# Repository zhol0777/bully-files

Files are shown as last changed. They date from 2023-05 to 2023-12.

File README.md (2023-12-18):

# bully-files

Bully is a keyboard designed by paaradiso keyboard design and zhol. It combines low typing angle, a plateless build, and modest but dignified design sensibilities. Its 13.5u width layout is designed for maximum compatibility with base kits that are missing minimum 40% keyboard support (“3-key”). Bully has a 22.4mm EKH, 4.0 degree angle, and bezels measuring 8mm and 3mm. 

The case files are provided in the [./case](./case/) directory, and alternative tops for HHKB layout (1.25u blocker) and WKL (1.25u blocker) are provided in their respective directories. 

This ran in a private run and public run by Coffee Break Keyboards in Q1 2023 and fulfilling Q2 2023.

## Required components
* Daughterboard
  * It is designed for [C3 Unified Daughterboard](https://github.com/Unified-Daughterboard/UDB-C-Legacy), but an updated daughterboard that takes JST-SH cables is provided [here](https://github.com/Unified-Daughterboard/UDB-C-JSH).
* Tadpoles
  * bully's PCB is fit into the case not with screws, but 8 injection molded rubber inserts named "tadpoles", from Geonworks.
  * [Files, courtesy Geon](https://geon.works/pages/tadpole-files)
* Screws
  * All screws are M2. Screws for daughterboard are 4mm, case screws are 6-ish mm.
* JST cable
  * As sold, bully took a 50mm 4-pin JST-SH cable. These cables are wired 1:1. I had no issues with Adafruit Qwiic JST SH cables sourced from Mouser. If you use an alternative connector on your PCB and daughterboard, you will need to ensure those cables are also 1:1.
* PCB
  * PCB edge cuts and plate files are provided in the [./misc](./misc/) directory. An electro-capacitive (commonly known as Topre, or NIZ Plum) compatible PCB is provided by sporkus [here](https://github.com/sporkus/capybully_keyboard). An alternative PCB compatible with Cherry MX and Alps switches is provided by sporkus [here](https://github.com/sporkus/bully2040_keyboard).
* Case feet.
  * bully uses [SKUF feet](https://github.com/Zambumon/SKUF).

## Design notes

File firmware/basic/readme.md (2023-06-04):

# mkh bully

* Keyboard Maintainer: [zhol0777](https://github.com/zhol0777)
* Hardware Supported: APM32F072
* Hardware Availability: [Coffee Break Keyboards](https://cbkbd.com/)

Make example for this keyboard (after setting up your build environment):

    qmk compile -kb zhol/bully -km default

Flashing example for this keyboard:

    qmk flash -kb zhol/bully -km default

See the [build environment setup](https://docs.qmk.fm/#/getting_started_build_tools) and the [make instructions](https://docs.qmk.fm/#/getting_started_make_guide) for more information. Brand new to QMK? Start with our [Complete Newbs Guide](https://docs.qmk.fm/#/newbs).

After flashing, you may see LIBUSB_ERROR_TIMEOUT; this is normal, simply tap the reset button once afterwards (or re-plug your PCB) and the keyboard should become operational again.

## Bootloader

Enter the bootloader in 3 ways:

* **Bootmagic reset**: Hold down the key at (0,0) in the matrix (usually the top left key or Escape) and plug in the keyboard
* **Physical reset button**: Press the button on the back of the PCB for at least three seconds
* **Keycode in layout**: Press the key mapped to `QK_BOOT` if it is available

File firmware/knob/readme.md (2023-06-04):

# mkh bully (now with knob)

* Keyboard Maintainer: [zhol0777](https://github.com/zhol0777)
* Hardware Supported: APM32F072
* Hardware Availability: Private Buy

Make example for this keyboard (after setting up your build environment):

    qmk compile -kb zhol/bully_knob -km default

Flashing example for this keyboard:

    qmk flash -kb zhol/bully_knob -km default

See the [build environment setup](https://docs.qmk.fm/#/getting_started_build_tools) and the [make instructions](https://docs.qmk.fm/#/getting_started_make_guide) for more information. Brand new to QMK? Start with our [Complete Newbs Guide](https://docs.qmk.fm/#/newbs).

After flashing, you may see LIBUSB_ERROR_TIMEOUT; this is normal, simply tap the reset button once afterwards (or re-plug your PCB) and the keyboard should become operational again.

## Bootloader

Enter the bootloader in 3 ways:

* **Bootmagic reset**: Hold down the key at (0,0) in the matrix (usually the top left key or Escape) and plug in the keyboard
* **Physical reset button**: Briefly press the button on the back of the PCB - some may have pads you must short instead
* **Keycode in layout**: Press the key mapped to `QK_BOOT` if it is available

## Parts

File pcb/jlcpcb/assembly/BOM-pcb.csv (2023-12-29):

Comment | Designator | Footprint | LCSC
10nF | C7 | C_0402_1005Metric | C15195
4.7uF | C10,C3,C8 | C_0402_1005Metric | C23733
100k | R2 | R_0402_1005Metric | C25741
10k | R1,R3 | R_0402_1005Metric | C25744
DB | J1 | JST_SH_SM04B-SRSS-TB_1x04-1MP_P1.00mm_Horizontal | C2845363
100nF | C1,C2,C4,C5 | C_0402_1005Metric | C307331
SW_Push | SW54 | SW_SPST_TL3342 | C318884
1uF | C11,C12,C6,C9 | C_0402_1005Metric | C52923
XC6206PxxxMR | U2 | SOT-23 | C5446
D_Small | D1,D10,D11,D12,D13,D14,D15,D16,D17,D18,D19,D2,D20,D21,D22,D23,D24,D25,D26,D27,D28,D29,D3,D30,D31,D32,D33,D34,D35,D36,D37,D38,D39,D4,D40,D41,D42,D43,D44,D45,D46,D5,D6,D7,D8,D9 | D_SOD-123 | C81598
2N7002 | Q1 | SOT-23 | C8545
STM32F072C8Tx | U1 | LQFP-48_7x7mm_P0.5mm | C915660
MX_SW_solder | SW10 | SW_MX_1u
MX_SW_solder | SW48 | SW_MX_1u
MX_SW_solder | SW49 | SW_MX_1.25u
MX_SW_solder | SW41 | SW_MX_1u
MX_SW_solder | SW25 | SW_MX_1u
MX_SW_solder | SW1 | SW_MX_1.75u
MX_SW_solder | SW57 | SW_MX_1.5u
MX_SW_solder | SW8 | SW_MX_1u
MX_SW_solder | SW60 | SW_MX_1.25u
MX_SW_solder | SW55 | SW_MX_1.25u
MX_SW_solder | SW59 | SW_MX_1.25u
MX_SW_solder | SW15 | SW_MX_1u
MX_SW_solder | SW36 | SW_MX_1u
MX_SW_solder | SW33 | SW_MX_1u
MX_SW_solder | SW6 | SW_MX_1.25u
MX_SW_solder | SW30 | SW_MX_1u
MX_SW_solder | SW31 | SW_MX_1u
MX_SW_solder | SW21 | SW_MX_1u
MX_SW_solder | SW7 | SW_MX_1.25u
MX_stab | S5 | STAB_MX_6u
MX_SW_solder | SW13 | SW_MX_1u
MX_SW_solder | SW5 | SW_MX_1u
MX_SW_solder | SW16 | SW_MX_1.25u
MX_SW_solder | SW24 | SW_MX_1u
MX_SW_solder | SW23 | SW_MX_1u
MX_SW_solder | SW46 | SW_MX_1u
MX_stab | S2 | STAB_MX_P_2.25u
MX_SW_solder | SW26 | SW_MX_1u
MX_stab | S8 | STAB_MX_P_2.75u
MX_SW_solder | SW29 | SW_MX_1u
MX_SW_solder | SW43 | SW_MX_1u
MX_SW_solder | SW37 | SW_MX_1u
MX_SW_solder | SW50 | SW_MX_1.25u
MX_SW_solder | SW2 | SW_MX_1.5u
MX_SW_solder | SW56 | SW_MX_1u
MX_SW_solder | SW47 | SW_MX_1u
MX_SW_solder | SW35 | SW_MX_1u
MX_stab | S4 | STAB_MX_P_2.25u
MX_SW_solder | SW42 | SW_MX_1u
MX_SW_solder | SW32 | SW_MX_1u
MX_SW_solder | SW19 | SW_MX_1u
MX_SW_solder | SW4 | SW_MX_1.75u_stp
MX_SW_solder | SW40 | SW_MX_1u
MX_SW_solder | SW9 | SW_MX_1u
MX_SW_solder | SW52 | SW_MX_1u
MX_stab | S7 | STAB_MX_P_3u
MX_SW_solder | SW12 | SW_MX_1.5u
MX_stab | S6 | STAB_MX_6.25u
MX_SW_solder | SW51 | SW_MX_1u
MX_SW_solder | SW34 | SW_MX_1u
MX_SW_solder | SW39 | SW_MX_1u
MX_SW_solder | SW53 | SW_MX_1.75u
MX_SW_solder | SW27 | SW_MX_1u
MX_stab | S1 | STAB_MX_P_2u
MX_SW_solder | SW22 | SW_MX_1u
MX_SW_solder | SW20 | SW_MX_1u
MX_SW_solder | SW45 | SW_MX_1.25u
MX_SW_solder | SW38 | SW_MX_1u
MX_SW_solder | SW44 | SW_MX_1.5u
MX_SW_solder | SW28 | SW_MX_1u
MX_SW_solder | SW17 | SW_MX_1u
MX_SW_solder | SW18 | SW_MX_1u
MX_SW_solder | SW14 | SW_MX_1u
MX_SW_solder | SW3 | SW_MX_1.5u
MX_stab | S3 | STAB_MX_P_3u
MX_SW_solder | SW11 | SW_MX_1.25u
MX_SW_solder | SW58 | SW_MX_1u
MX_SW_solder | SW61 | SW_MX_1u
MX_stab | S9 | STAB_MX_P_2.25u

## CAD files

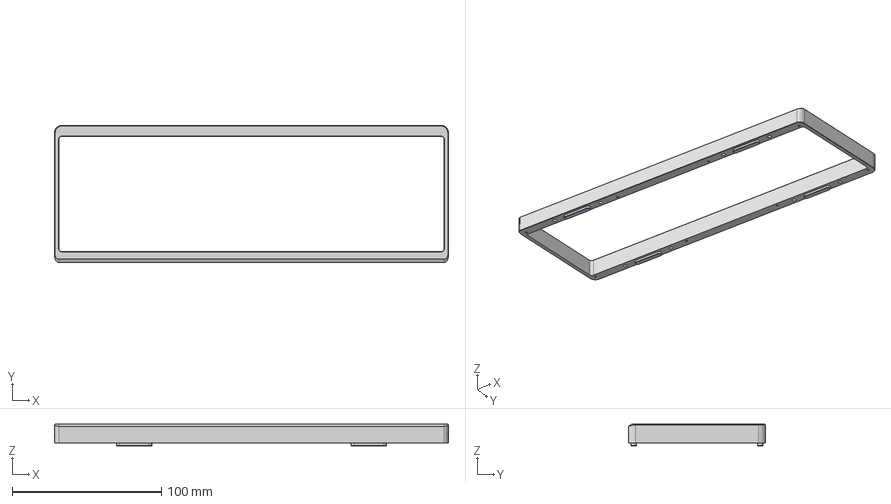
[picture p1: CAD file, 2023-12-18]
case/Top.step
264.1 x 92.1 x 14.7 mm

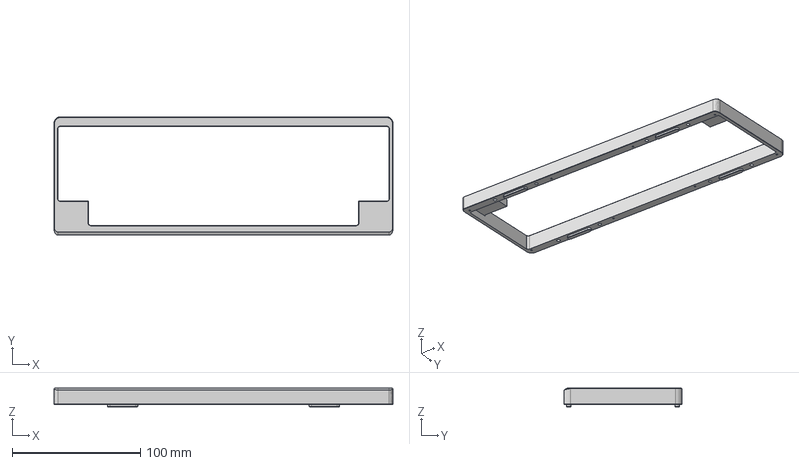
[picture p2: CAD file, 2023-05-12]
hhkb_top/Top.step
264.1 x 92.1 x 14.7 mm

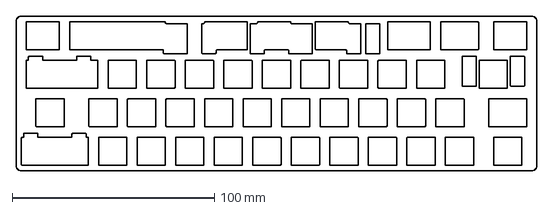
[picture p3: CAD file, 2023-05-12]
misc/plate-2.dxf
257.2 x 76.2 mm

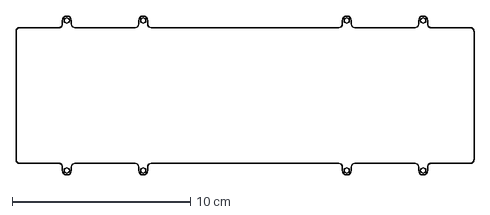
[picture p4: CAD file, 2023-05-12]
pcb/edgecuts.dxf
25.7 x 8.92 cm

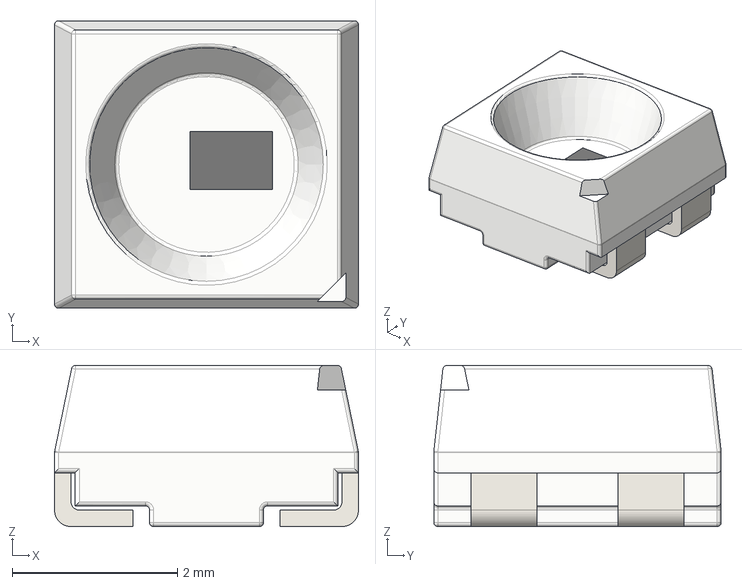
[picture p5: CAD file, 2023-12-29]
pcb/marbastlib/3d/LED_WS2812B-MINI.step
3.68 x 3.48 x 1.95 mm

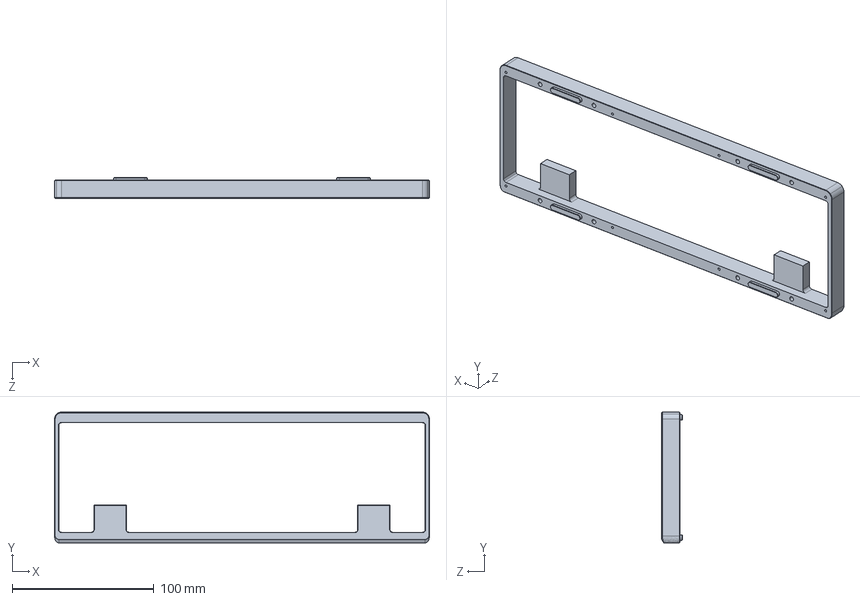
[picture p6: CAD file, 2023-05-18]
wkl_top/wkl_6u.STEP
264.1 x 92.1 x 14.7 mm

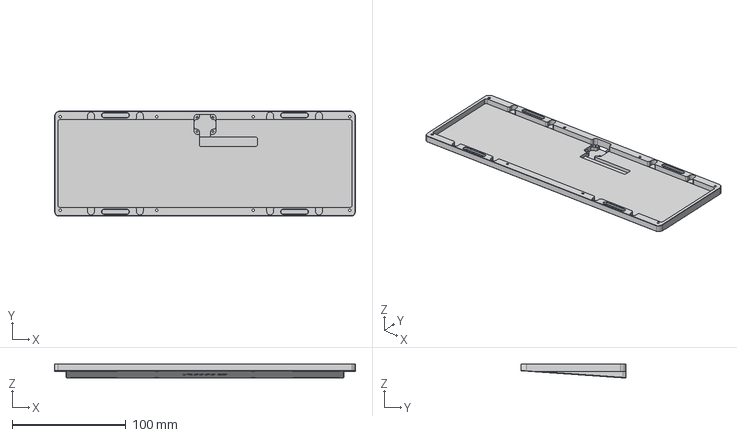
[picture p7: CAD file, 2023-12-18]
case/Bottom-gb.step
264.1 x 92.1 x 12.4 mm

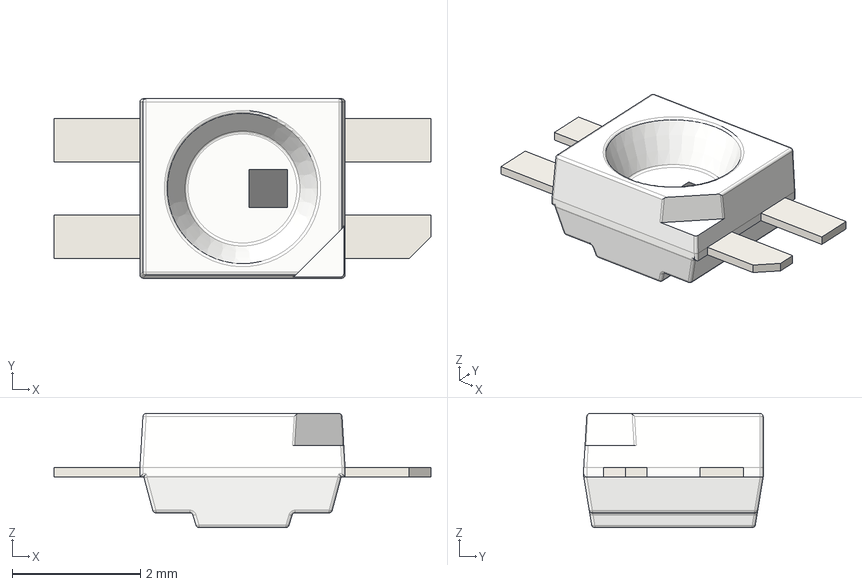
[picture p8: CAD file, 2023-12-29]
pcb/marbastlib/3d/LED_SK6812MINI-E.step
5.88 x 2.80 x 1.78 mm

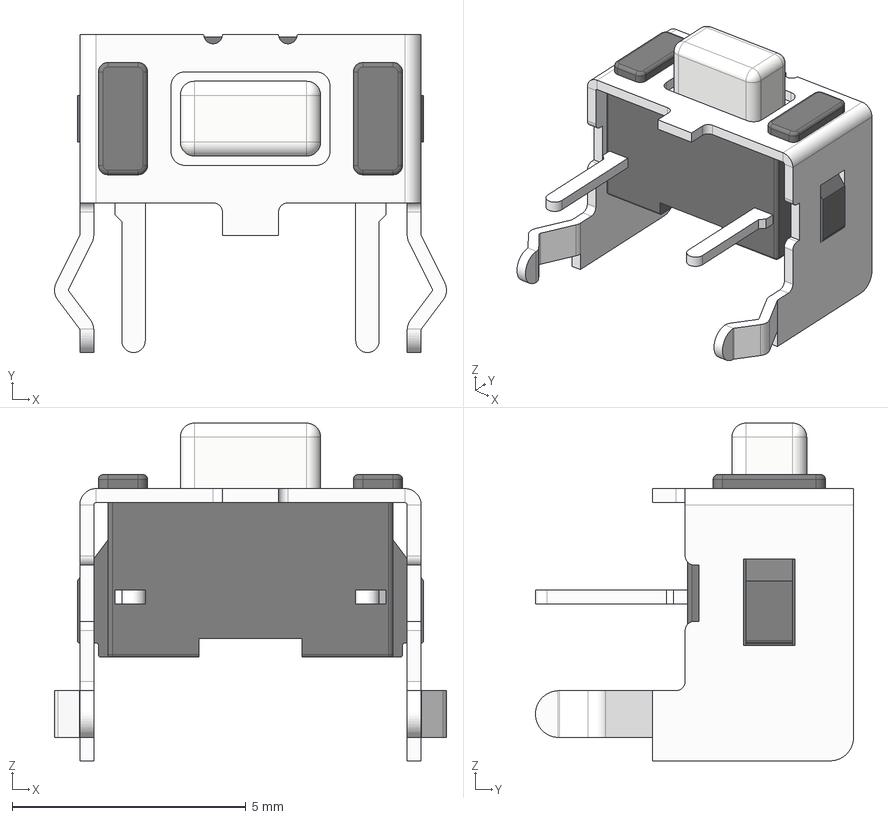
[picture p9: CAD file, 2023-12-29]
pcb/marbastlib/3d/SW_SKHLLC.step
8.38 x 6.80 x 7.22 mm

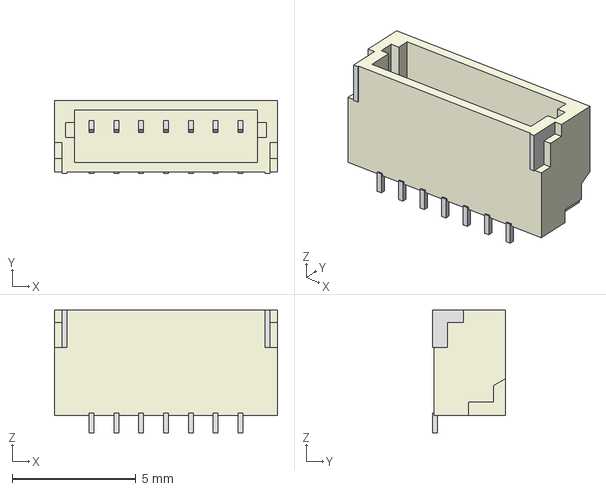
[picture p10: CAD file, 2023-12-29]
pcb/marbastlib/3d/CON_SM07B-SRSS-TB.step
9.00 x 2.96 x 4.95 mm

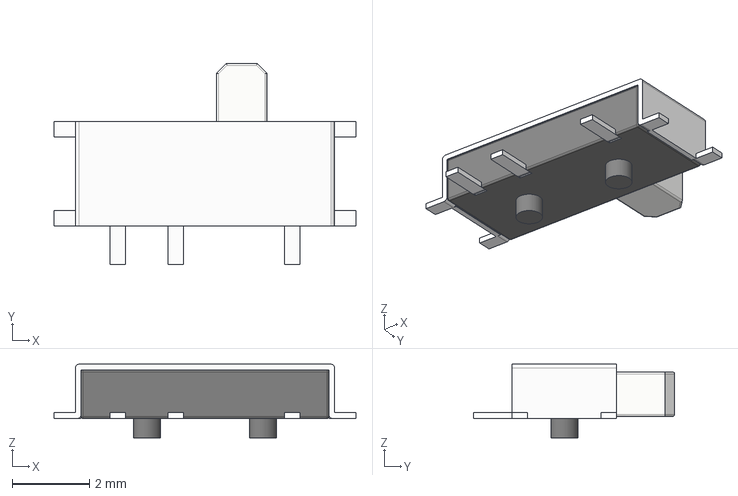
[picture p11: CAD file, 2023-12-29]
pcb/marbastlib/3d/SW_MSK12C02.step
7.80 x 5.20 x 1.90 mm

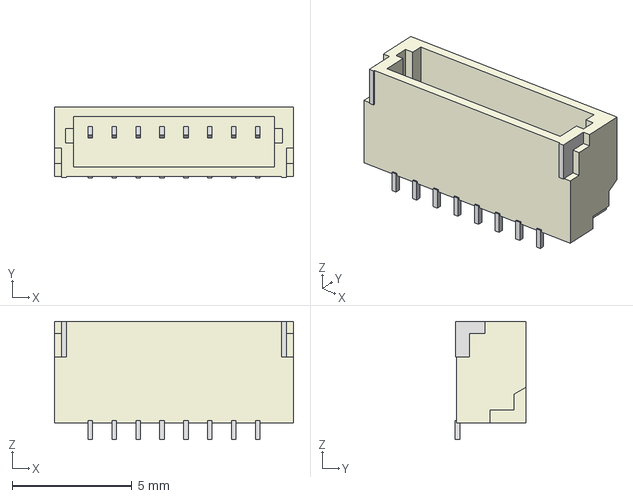
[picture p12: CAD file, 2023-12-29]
pcb/marbastlib/3d/CON_SM08B-SRSS-TB.step
10.0 x 2.96 x 4.95 mm

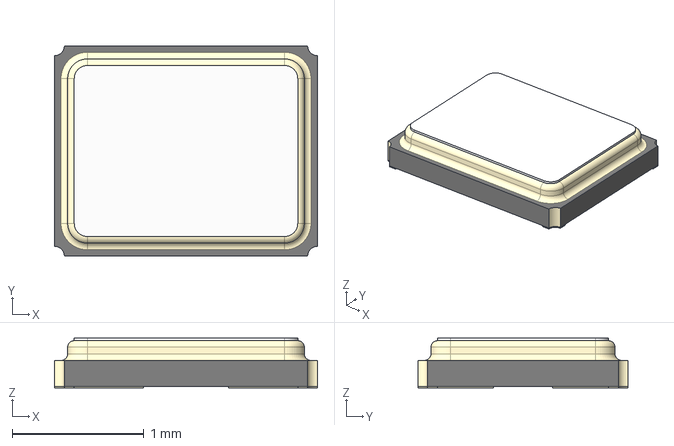
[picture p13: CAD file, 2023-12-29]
pcb/marbastlib/3d/Crystal_FA-128.step
2.00 x 1.60 x 0.38 mm

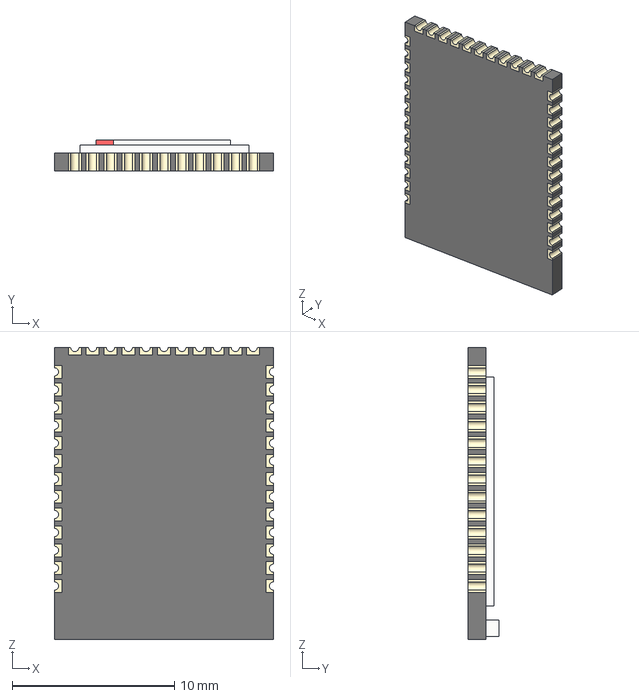
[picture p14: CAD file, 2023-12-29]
pcb/marbastlib/3d/holyiot_18010_nRF52840.step
13.5 x 1.92 x 18.0 mm

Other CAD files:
pcb/marbastlib/3d/MSK12C02.step
pcb/marbastlib/3d/ROT_EC11E.step
pcb/marbastlib/3d/SW_SSSS213100.step
pcb/marbastlib/3d/ROT_EC11N.step
pcb/marbastlib/3d/CON_BM02B-ACHSS.step
pcb/marbastlib/3d/CON_MJ-4PP-9.step
pcb/marbastlib/3d/CON_SM02B-SRSS-TB.step
pcb/marbastlib/3d/CON_SM04B-SRSS-TB.step
pcb/marbastlib/3d/CON_SM05B-SRSS-TB.step
pcb/marbastlib/3d/CON_SM06B-SRSS-TB.step
pcb/marbastlib/3d/CON_SM13B-SRSS-TB.step
pcb/marbastlib/3d/CON_TYPE-C-31-M-12.step
pcb/marbastlib/3d/CON_TYPE-C-31-M-14.step
pcb/marbastlib/3d/HS_Kailh_Choc.step
pcb/marbastlib/3d/HS_Kailh_MX.step
pcb/marbastlib/3d/LED_WS2812_2020.step
pcb/marbastlib/3d/PNT_RKJXU1210006.step
pcb/marbastlib/3d/PNT_psp1000.step
pcb/marbastlib/3d/SW_ESP3020.step
pcb/marbastlib/3d/SW_SSSS223900.step
pcb/marbastlib/3d/moko_mk08a_nRF52840.step

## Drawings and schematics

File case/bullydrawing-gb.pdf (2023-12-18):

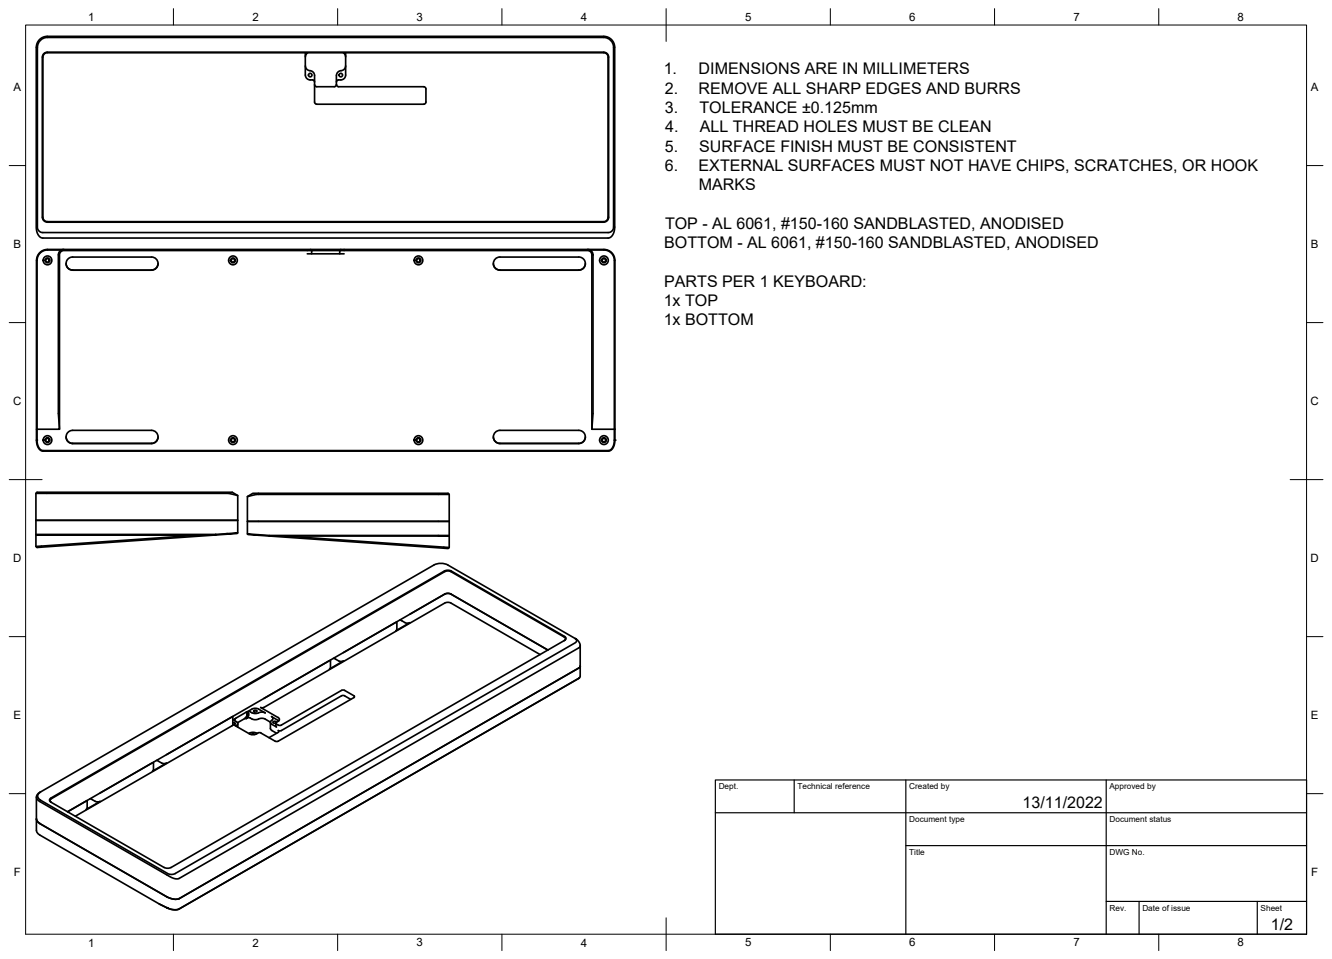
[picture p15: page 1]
Title; DWG No.; Rev.; Date of issue; Sheet

1. DIMENSIONS ARE IN MILLIMETERS
2. REMOVE ALL SHARP EDGES AND BURRS
3. TOLERANCE ±0.125mm
4. ALL THREAD HOLES MUST BE CLEAN
5. SURFACE FINISH MUST BE CONSISTENT
6. EXTERNAL SURFACES MUST NOT HAVE CHIPS, SCRATCHES, OR HOOK
MARKS

TOP - AL 6061, #150-160 SANDBLASTED, ANODISED
BOTTOM - AL 6061, #150-160 SANDBLASTED, ANODISED

PARTS PER 1 KEYBOARD:
1x TOP
1x BOTTOM

Dept. | Technical reference | Created by 13/11/2022 | Approved by

Document type | Document status

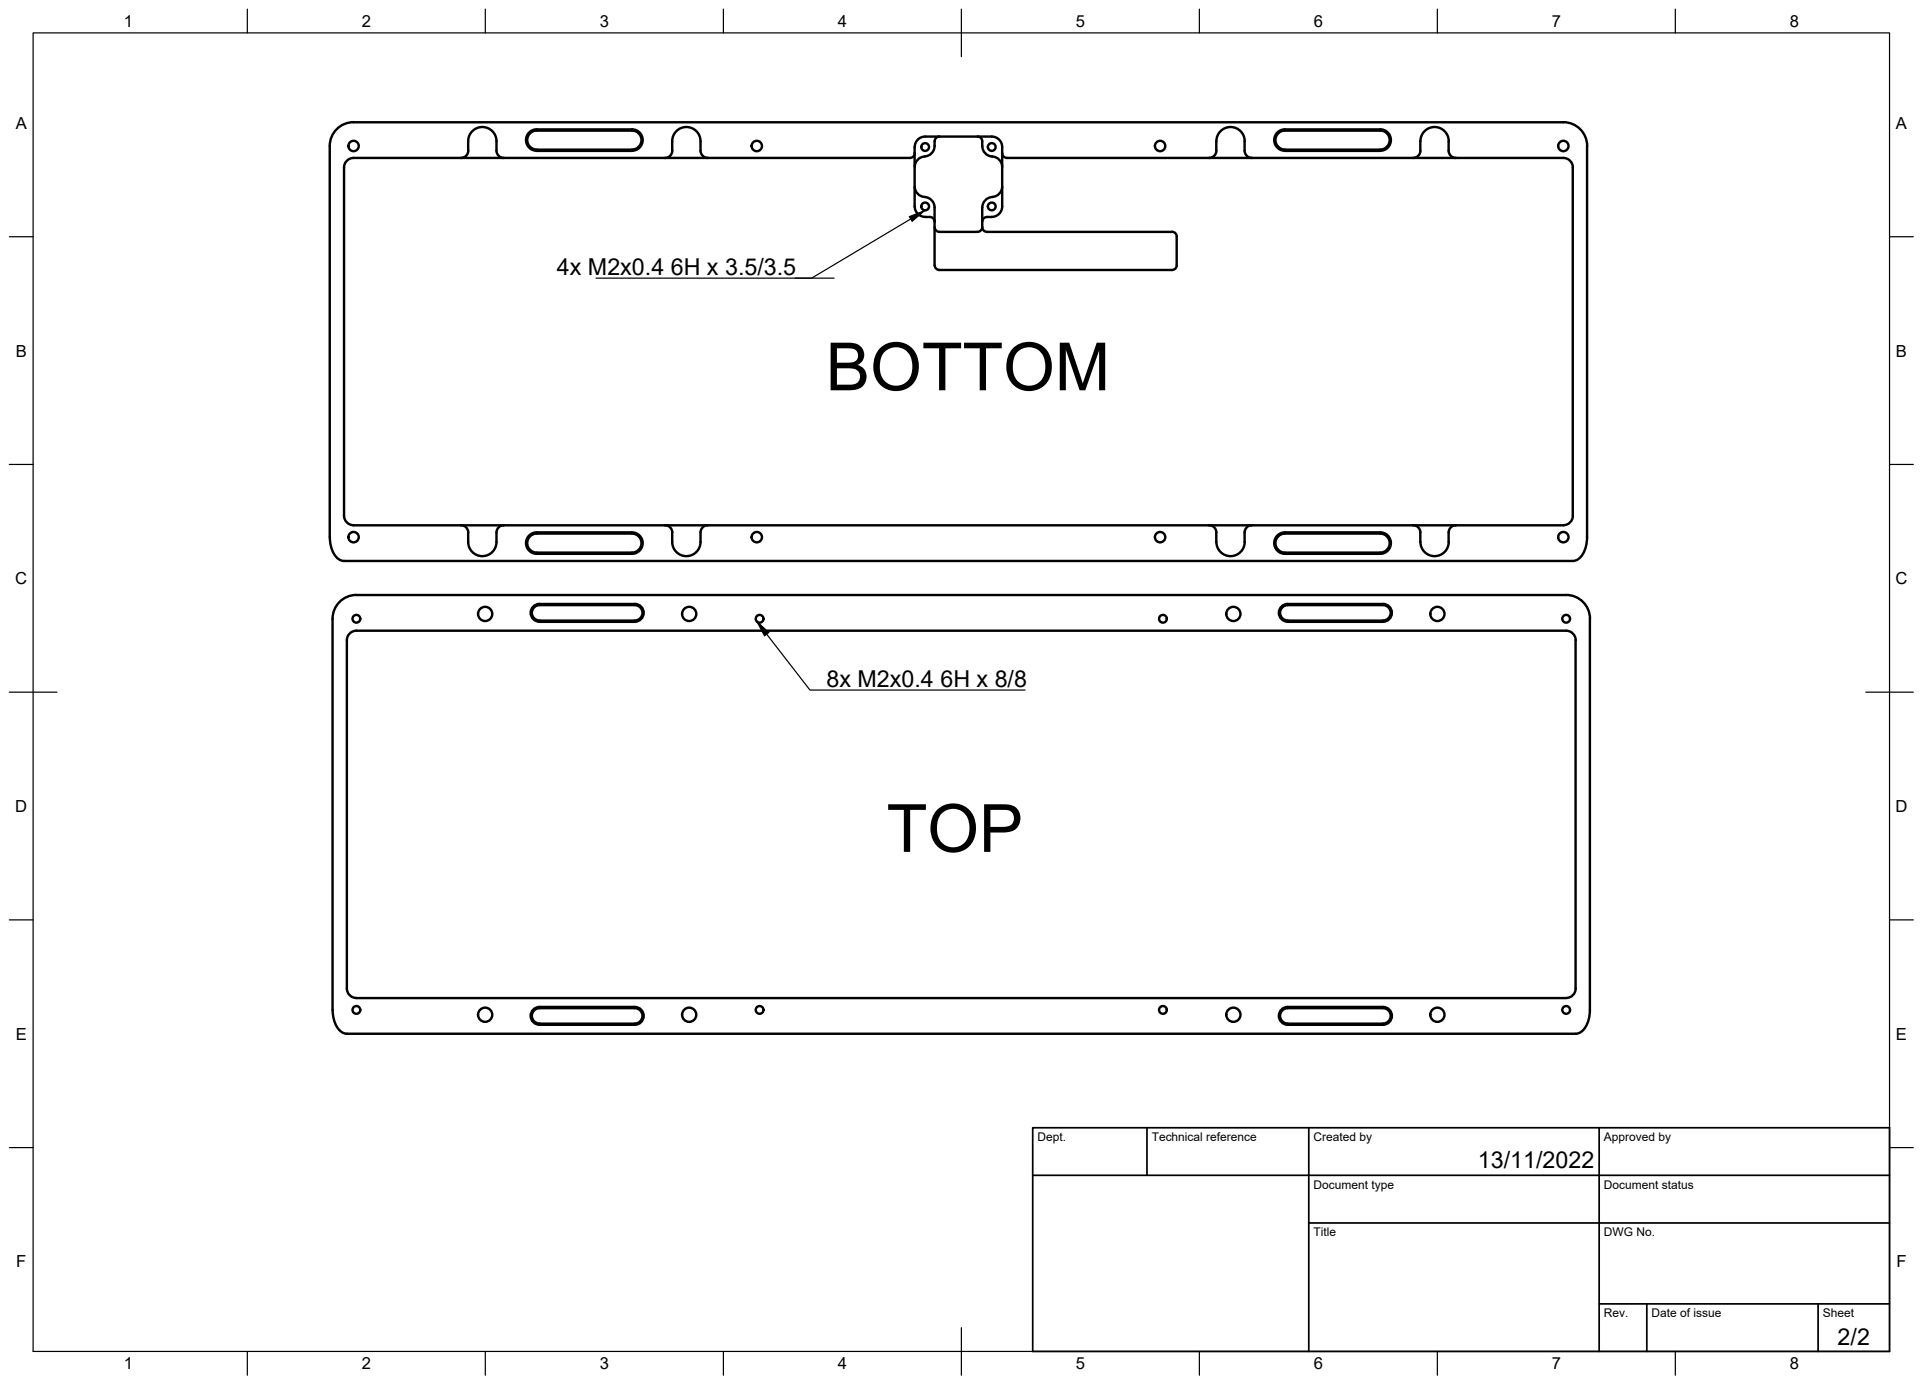
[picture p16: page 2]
Title; DWG No.; Rev.; Date of issue; Sheet

Dept. | Technical reference | Created by 13/11/2022 | Approved by

Document type | Document status

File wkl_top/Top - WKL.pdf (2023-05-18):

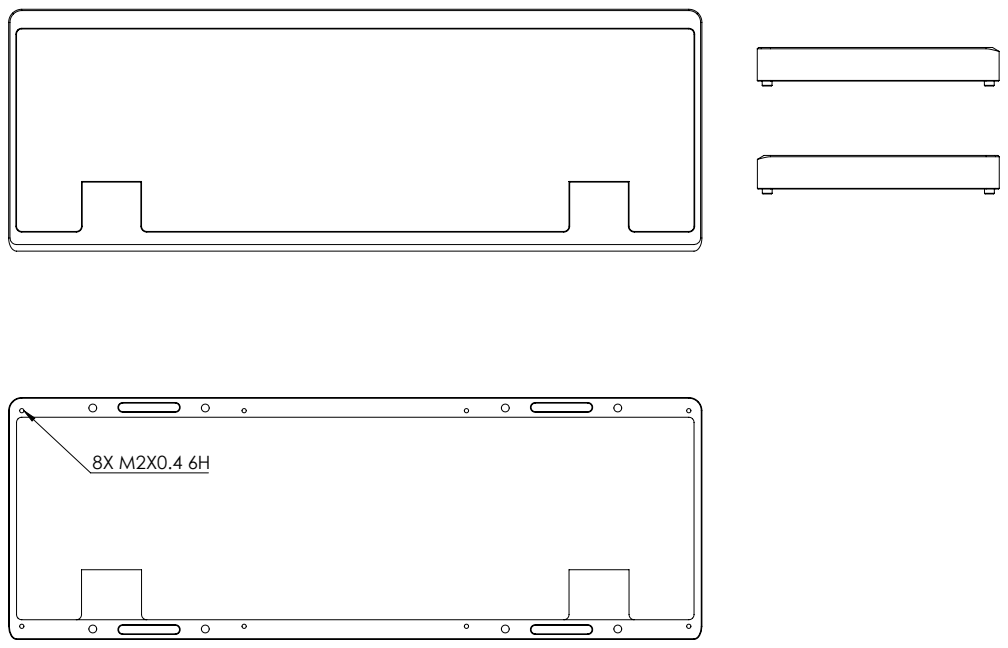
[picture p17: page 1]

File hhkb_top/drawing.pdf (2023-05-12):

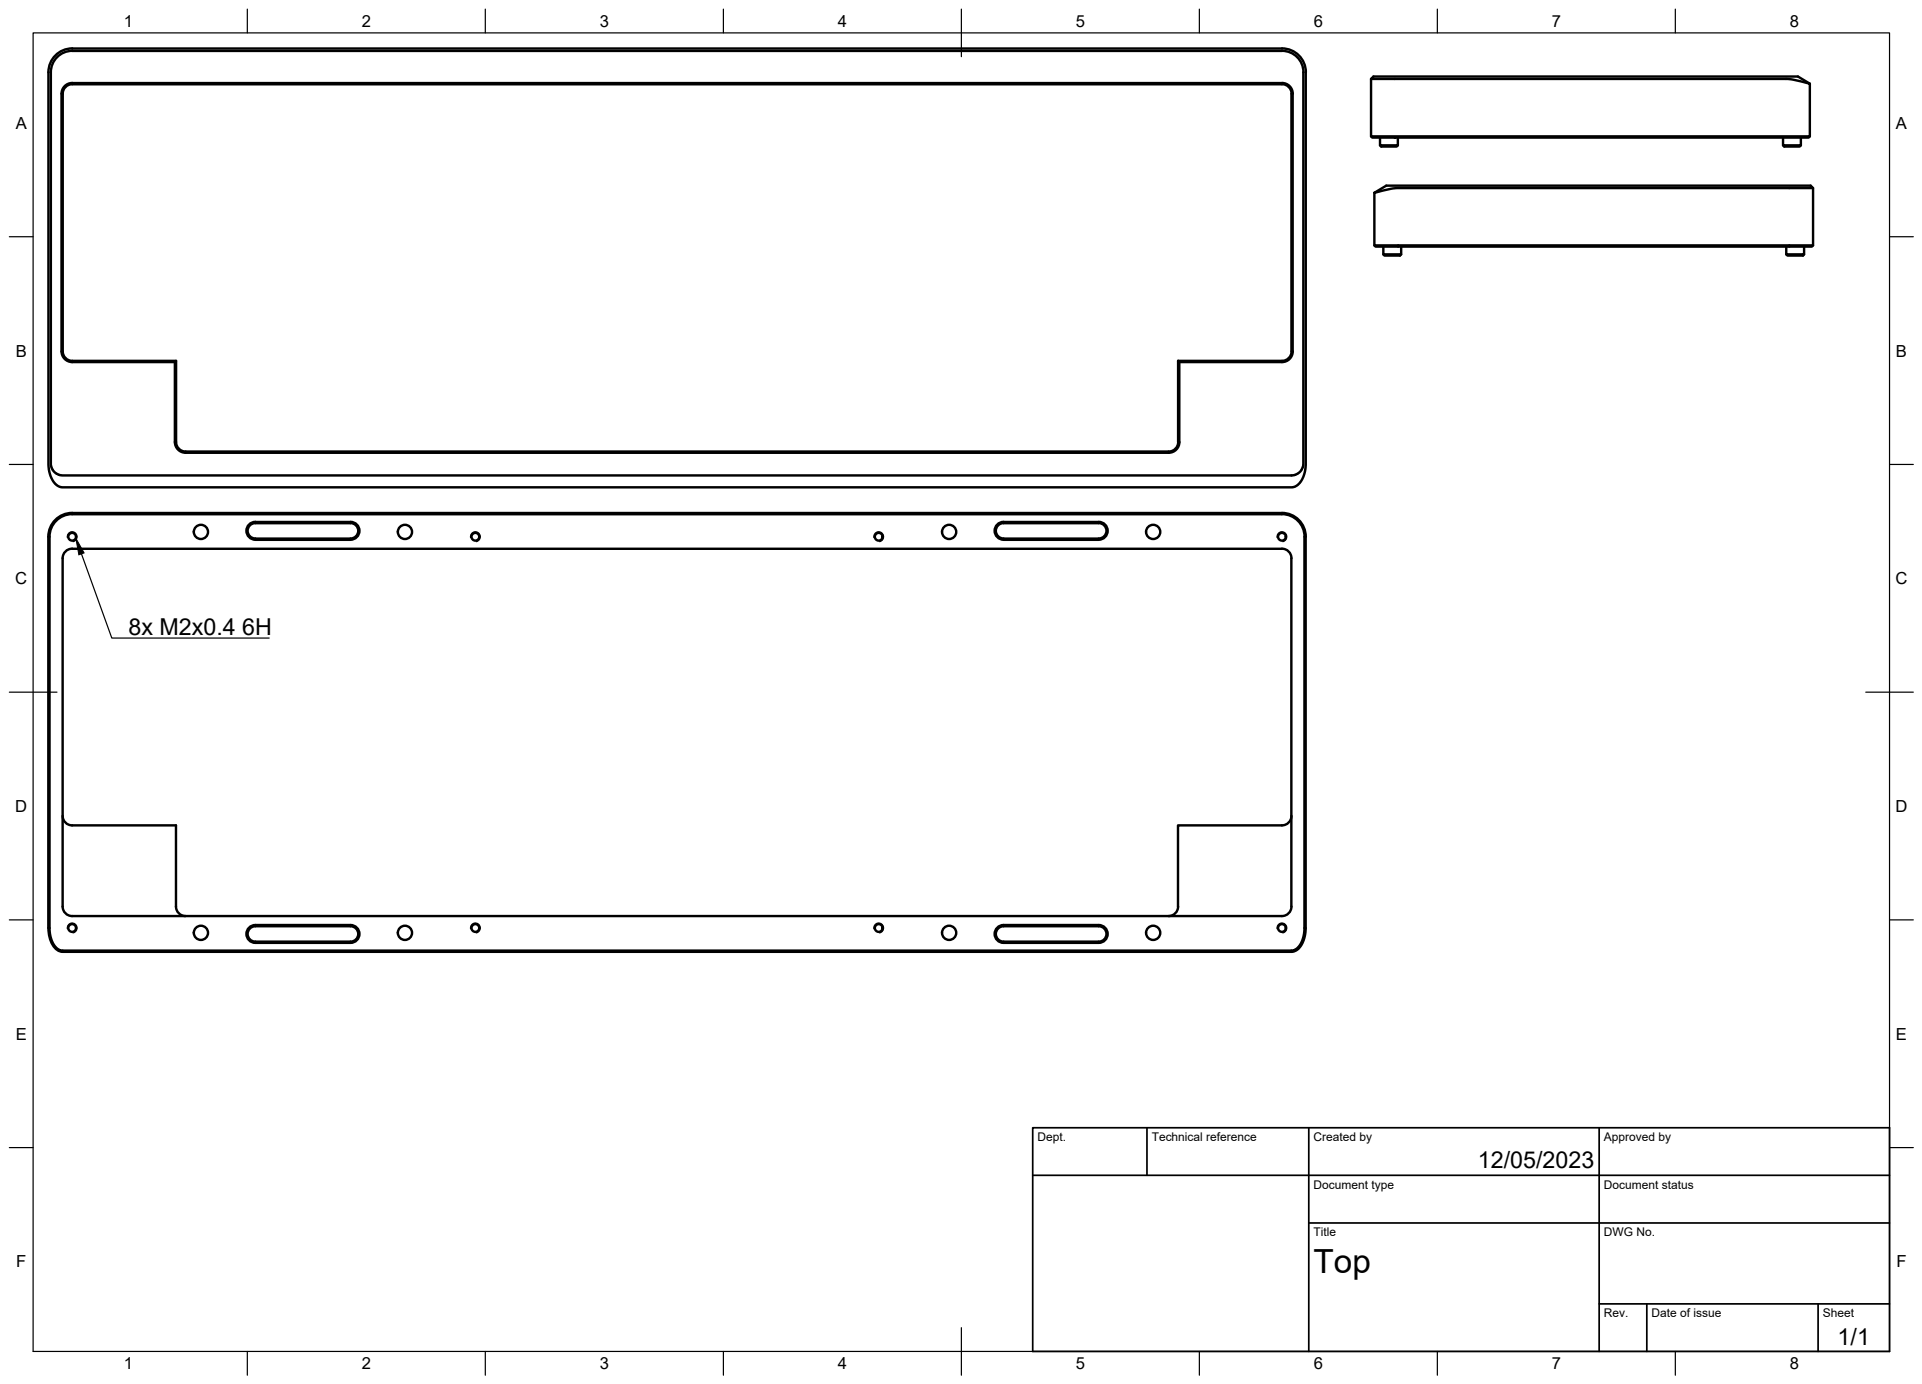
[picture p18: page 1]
Title; DWG No.; Rev.; Date of issue; Sheet

Dept. | Technical reference | Created by 12/05/2023 | Approved by

Document type | Document status

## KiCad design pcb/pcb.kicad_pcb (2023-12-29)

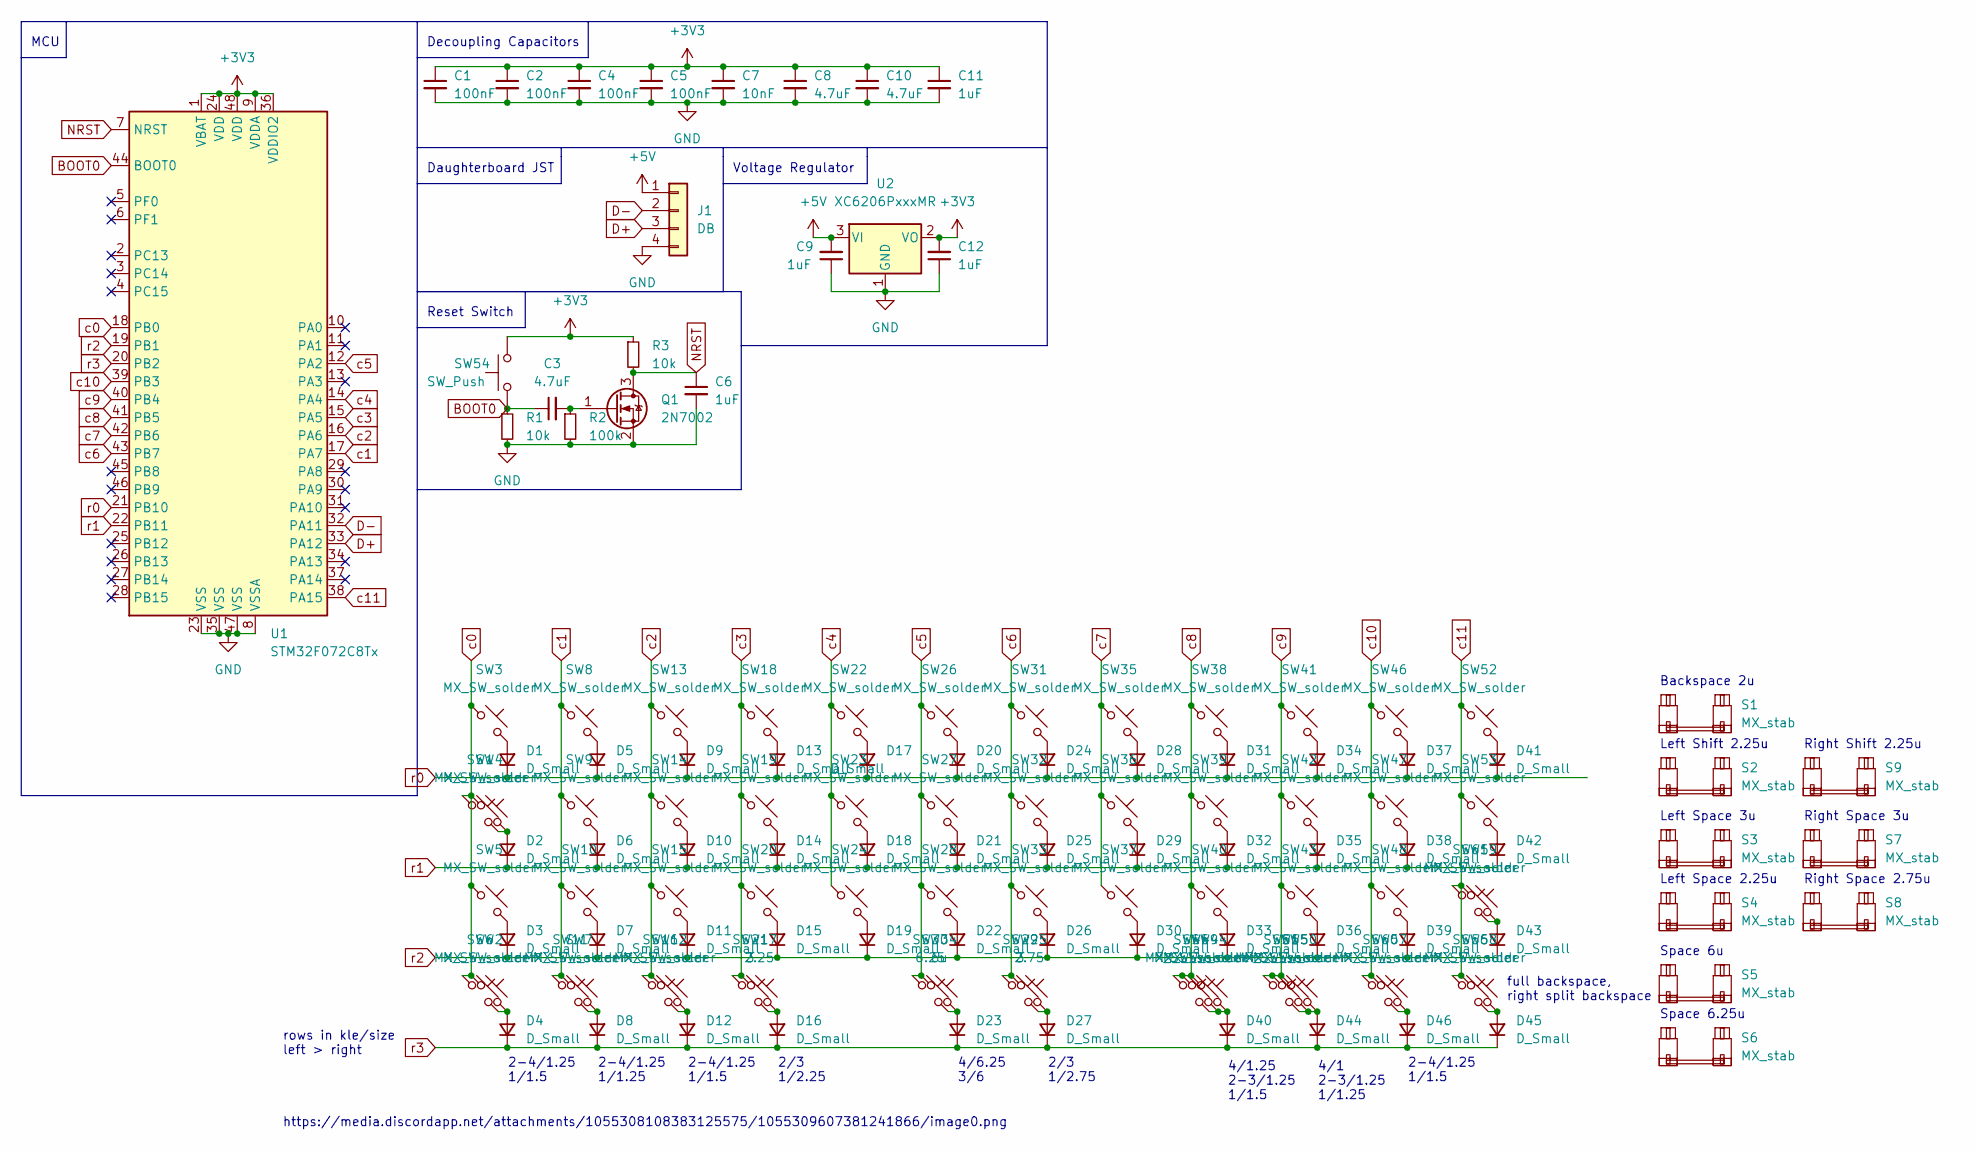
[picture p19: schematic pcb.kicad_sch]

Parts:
C1, C2, C4, C5: 100nF; C_0402_1005Metric
C3, C8, C10: 4.7uF; C_0402_1005Metric
C6, C9, C11, C12: 1uF; C_0402_1005Metric
C7: 10nF; C_0402_1005Metric
D1, D2, D3, D4, D5, D6, D7, D8, D9, D10, D11, D12, D13, D14, D15, D16, D17, D18, D19, D20, D21, D22, D23, D24, D25, D26, D27, D28, D29, D30, D31, D32, D33, D34, D35, D36, D37, D38, D39, D40, D41, D42, D43, D44, D45, D46: D_Small; D_SOD-123
J1: DB; JST_SH_SM04B-SRSS-TB_1x04-1MP_P1.00mm_Horizontal
Q1: 2N7002; SOT-23
R1, R3: 10k; R_0402_1005Metric
R2: 100k; R_0402_1005Metric
S1: MX_stab; STAB_MX_P_2u
S2, S4, S9: MX_stab; STAB_MX_P_2.25u
S3, S7: MX_stab; STAB_MX_P_3u
S5: MX_stab; STAB_MX_6u
S6: MX_stab; STAB_MX_6.25u
S8: MX_stab; STAB_MX_P_2.75u
SW1, SW53: MX_SW_solder; SW_MX_1.75u
SW2, SW3, SW12, SW44, SW57: MX_SW_solder; SW_MX_1.5u
SW4: MX_SW_solder; SW_MX_1.75u_stp
SW5, SW8, SW9, SW10, SW13, SW14, SW15, SW18, SW19, SW20, SW22, SW23, SW24, SW26, SW27, SW28, SW31, SW32, SW33, SW35, SW36, SW37, SW38, SW39, SW40, SW41, SW42, SW43, SW46, SW47, SW48, SW51, SW52, SW56, SW58, SW61: MX_SW_solder; SW_MX_1u
SW6, SW7, SW11, SW16, SW45, SW49, SW50, SW55, SW59, SW60: MX_SW_solder; SW_MX_1.25u
SW17: 2.25; SW_MX_1u
SW21, SW29: 3; SW_MX_1u
SW25: 2.75; SW_MX_1u
SW30: 6.25; SW_MX_1u
SW34: 6u; SW_MX_1u
SW54: SW_Push; SW_SPST_TL3342
U1: STM32F072C8Tx; LQFP-48_7x7mm_P0.5mm
U2: XC6206PxxxMR; SOT-23

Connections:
+3V3: C1.1, C2.1, C4.1, C5.1, C7.1, C8.1, C10.1, C11.1, C12.2, R3.1, SW54.2, U1.1 (VBAT), U1.9 (VDDA), U1.24 (VDD), U1.36 (VDDIO2), U1.48 (VDD), U2.2 (VO)
+5V: C9.2, J1.1, U2.3 (VI)
BOOT0: C3.1, R1.1, SW54.1, U1.44 (BOOT0)
D+: J1.3, U1.33 (PA12)
D-: J1.2, U1.32 (PA11)
GND: C1.2, C2.2, C4.2, C5.2, C6.2, C7.2, C8.2, C9.1, C10.2, C11.2, C12.1, J1.4, Q1.2 (S), R1.2, R2.2, U1.8 (VSSA), U1.23 (VSS), U1.35 (VSS), U1.47 (VSS), U2.1 (GND)
NRST: C6.1, Q1.3 (D), R3.2, U1.7 (NRST)
unnamed: D1.2 (A), SW3.2
unnamed: D2.2 (A), SW1.2, SW4.2
unnamed: D3.2 (A), SW5.2
unnamed: D4.2 (A), SW2.2, SW6.2
unnamed: D5.2 (A), SW8.2
unnamed: D6.2 (A), SW9.2
unnamed: D7.2 (A), SW10.2
unnamed: D8.2 (A), SW7.2, SW11.2
unnamed: D9.2 (A), SW13.2
unnamed: D10.2 (A), SW14.2
unnamed: D11.2 (A), SW15.2
unnamed: D12.2 (A), SW12.2, SW16.2
unnamed: D13.2 (A), SW18.2
unnamed: D14.2 (A), SW19.2
unnamed: D15.2 (A), SW20.2
unnamed: D16.2 (A), SW17.2, SW21.2
unnamed: D17.2 (A), SW22.2
unnamed: D18.2 (A), SW23.2
unnamed: D19.2 (A), SW24.2
unnamed: D20.2 (A), SW26.2
unnamed: D21.2 (A), SW27.2
unnamed: D22.2 (A), SW28.2
unnamed: D23.2 (A), SW30.2, SW34.2
unnamed: D24.2 (A), SW31.2
unnamed: D25.2 (A), SW32.2
unnamed: D26.2 (A), SW33.2
unnamed: D27.2 (A), SW25.2, SW29.2
unnamed: D28.2 (A), SW35.2
unnamed: D29.2 (A), SW36.2
unnamed: D30.2 (A), SW37.2
unnamed: D31.2 (A), SW38.2
unnamed: D32.2 (A), SW39.2
unnamed: D33.2 (A), SW40.2
unnamed: D34.2 (A), SW41.2
unnamed: D35.2 (A), SW42.2
unnamed: D36.2 (A), SW43.2
unnamed: D37.2 (A), SW46.2
unnamed: D38.2 (A), SW47.2
unnamed: D39.2 (A), SW48.2
unnamed: D40.2 (A), SW44.2, SW45.2, SW49.2
unnamed: D41.2 (A), SW52.2
unnamed: D42.2 (A), SW53.2
unnamed: D43.2 (A), SW59.2, SW61.2
unnamed: D44.2 (A), SW50.2, SW51.2, SW55.2
unnamed: D45.2 (A), SW56.2, SW58.2
unnamed: D46.2 (A), SW57.2, SW60.2
unnamed: C3.2, Q1.1 (G), R2.1
c0: SW1.1, SW2.1, SW3.1, SW4.1, SW5.1, SW6.1, U1.18 (PB0)
c1: SW7.1, SW8.1, SW9.1, SW10.1, SW11.1, U1.17 (PA7)
c2: SW12.1, SW13.1, SW14.1, SW15.1, SW16.1, U1.16 (PA6)
c3: SW17.1, SW18.1, SW19.1, SW20.1, SW21.1, U1.15 (PA5)
c4: SW22.1, SW23.1, SW24.1, U1.14 (PA4)
c5: SW26.1, SW27.1, SW28.1, SW30.1, SW34.1, U1.12 (PA2)
c6: SW25.1, SW29.1, SW31.1, SW32.1, SW33.1, U1.43 (PB7)
c7: SW35.1, SW36.1, SW37.1, U1.42 (PB6)
c8: SW38.1, SW39.1, SW40.1, SW44.1, SW45.1, SW49.1, U1.41 (PB5)
c9: SW41.1, SW42.1, SW43.1, SW50.1, SW51.1, SW55.1, U1.40 (PB4)
c10: SW46.1, SW47.1, SW48.1, SW57.1, SW60.1, U1.39 (PB3)
c11: SW52.1, SW53.1, SW56.1, SW58.1, SW59.1, SW61.1, U1.38 (PA15)
r0: D1.1 (K), D5.1 (K), D9.1 (K), D13.1 (K), D17.1 (K), D20.1 (K), D24.1 (K), D28.1 (K), D31.1 (K), D34.1 (K), D37.1 (K), D41.1 (K), U1.21 (PB10)
r1: D2.1 (K), D6.1 (K), D10.1 (K), D14.1 (K), D18.1 (K), D21.1 (K), D25.1 (K), D29.1 (K), D32.1 (K), D35.1 (K), D38.1 (K), D42.1 (K), U1.22 (PB11)
r2: D3.1 (K), D7.1 (K), D11.1 (K), D15.1 (K), D19.1 (K), D22.1 (K), D26.1 (K), D30.1 (K), D33.1 (K), D36.1 (K), D39.1 (K), D43.1 (K), U1.19 (PB1)
r3: D4.1 (K), D8.1 (K), D12.1 (K), D16.1 (K), D23.1 (K), D27.1 (K), D40.1 (K), D44.1 (K), D45.1 (K), D46.1 (K), U1.20 (PB2)

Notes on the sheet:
Backspace 2u
https://media.discordapp.net/attachments/1055308108383125575/1055309607381241866/image0.png
2-4/1.25 1/1.5
Daughterboard JST
Left Space 3u
4/1.25 2-3/1.25 1/1.5
full backspace, right split backspace
Voltage Regulator
2-4/1.25 1/1.25
Decoupling Capacitors
Right Shift 2.25u
2/3 1/2.75
rows in kle/size left > right
Right Space 3u
Space 6.25u
2/3 1/2.25
Reset Switch
4/1 2-3/1.25 1/1.25
Space 6u
Left Shift 2.25u
4/6.25 3/6
Right Space 2.75u
MCU
Left Space 2.25u

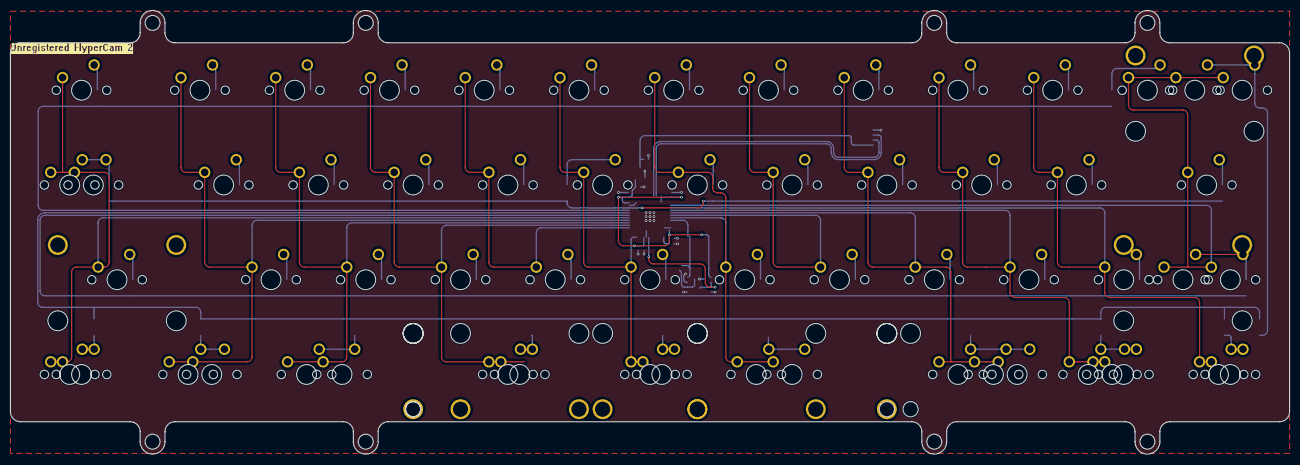
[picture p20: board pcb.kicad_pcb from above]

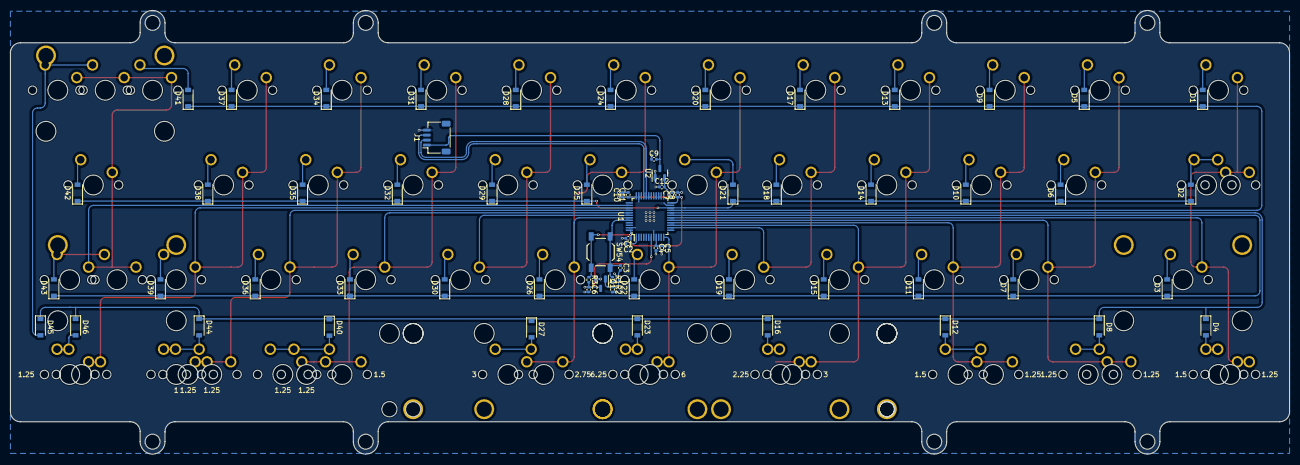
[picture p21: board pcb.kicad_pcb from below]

Board: 2 copper layers, 257.2 x 89.2 mm, 135 parts (66 on the bottom side), 70 nets.

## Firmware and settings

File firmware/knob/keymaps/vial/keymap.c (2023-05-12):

// Copyright 2022 zhol
// SPDX-License-Identifier: GPL-2.0-or-later

#include QMK_KEYBOARD_H

const uint16_t PROGMEM keymaps[][MATRIX_ROWS][MATRIX_COLS] = {
    [0] = LAYOUT(
        KC_TAB,        KC_Q,    KC_W,    KC_E,          KC_R, KC_T,   KC_Y,   KC_U, KC_I,    KC_O,    KC_P,    KC_DEL,        KC_BSPC,
        LT(2, KC_ESC), KC_A,    KC_S,    KC_D,          KC_F, KC_G,   KC_H,   KC_J, KC_K,    KC_L,    KC_SCLN, KC_QUOT,
        KC_LSFT,       KC_Z,    KC_X,    KC_C,          KC_V, KC_B,   KC_N,   KC_M, KC_COMM, KC_DOT,  KC_SLSH, RSFT_T(KC_ENT),
        KC_LCTL,       KC_LGUI, KC_LALT, LT(1, KC_SPC),       KC_SPC, KC_SPC,       KC_RALT, KC_RGUI, KC_RCTL
    ),
    [1] = LAYOUT(
        KC_GRV,  KC_1,    KC_2,    KC_3,    KC_4,    KC_5,    KC_6,          KC_7,    KC_8,    KC_9,    KC_0,    KC_TRNS, QK_BOOT,
        KC_TRNS, KC_TRNS, KC_TRNS, KC_TRNS, KC_TRNS, KC_MINS, KC_EQL,        KC_TRNS, KC_TRNS, KC_TRNS, KC_TRNS, KC_BSLS,
        KC_TRNS, KC_TRNS, KC_TRNS, KC_TRNS, KC_TRNS, KC_LBRC, KC_RBRC,       KC_TRNS, KC_TRNS, KC_TRNS, KC_PGUP, KC_TRNS,
        KC_TRNS, KC_TRNS, KC_TRNS, KC_TRNS,          KC_TRNS, LT(2, KC_SPC),          KC_HOME, KC_PGDN, KC_END
    ),
    [2] = LAYOUT(
        KC_TRNS, KC_TRNS, KC_UP,   KC_TRNS, KC_PGUP, KC_TRNS, KC_F1,   KC_F2,   KC_F3,   KC_F4,   KC_F5,   KC_F6,    KC_TRNS,
        KC_TRNS, KC_LEFT, KC_DOWN, KC_RGHT, KC_PGDN, KC_TRNS, KC_F7,   KC_F8,   KC_F9,   KC_F10,  KC_F11,  KC_F12,  
        KC_TRNS, KC_TRNS, KC_TRNS, KC_TRNS, KC_TRNS, KC_TRNS, KC_TRNS, KC_TRNS, KC_TRNS, KC_TRNS, KC_TRNS, KC_TRNS,
        KC_TRNS, KC_TRNS, KC_TRNS, KC_TRNS,          KC_TRNS, KC_TRNS,          KC_TRNS, KC_TRNS, KC_TRNS
    )
};


#if defined(ENCODER_MAP_ENABLE)
const uint16_t PROGMEM encoder_map[][NUM_ENCODERS][2] = {
    [0] =   { ENCODER_CCW_CW(KC_MS_WH_UP, KC_MS_WH_DOWN)  },
    [1] =   { ENCODER_CCW_CW(RGB_HUD, RGB_HUI)  },
    [2] =   { ENCODER_CCW_CW(RGB_VAD, RGB_VAI)  },
    //                  Encoder 1                 
};
#endif

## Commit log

2023-05-18 Adding 1.25 WKL Top
    Who would use this?
    [Top - WKL.STEP]
2023-05-18 Rename Top - WKL.STEP to wkl_6u.STEP
    [wkl_6u.STEP]
2023-12-18 add case files
    [Bottom-gb.step, Top.step]
